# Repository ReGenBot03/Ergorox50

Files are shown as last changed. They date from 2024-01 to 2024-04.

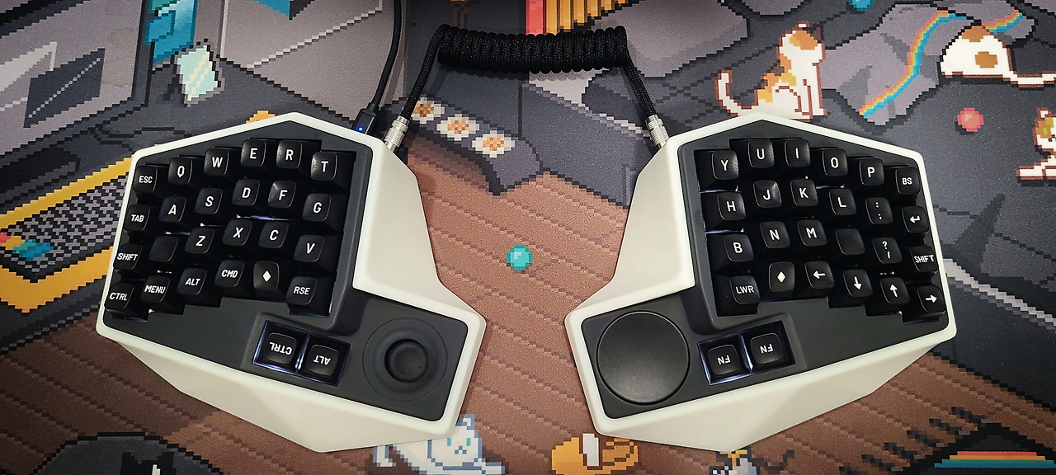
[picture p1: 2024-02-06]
Pics/Title.png

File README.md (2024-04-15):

Title
# ErgoRox50 - Split keyboard with joystick & Trackpad

### Schematic :

Schematics
-------------

### Encloser :

Render
-------------

### BOM :

|Item|Quantity|Link|
|---|---|---|
|minimal-fpc-i2c-pcb*|1|https://github.com/keyboard-magpie/minimal-fpc-i2c-pcb|
|Kailh Joystick|1|https://ko.aliexpress.com/item/32982601039.html|
|Joystick Cap (XBox 360)|1|https://ko.aliexpress.com/item/1005004579062558.html|
|TTC Hotswap Socket|52|https://ko.aliexpress.com/item/1005004922507959.html|
|SK6803 MINI-E 3MA|52|https://ko.aliexpress.com/item/1005003636565847.html|
|SOD123 Diode (1N4148W T4)|53|https://ko.aliexpress.com/item/32921490945.html|
|C Type Socket (Male & Female Set)|2|https://ko.aliexpress.com/item/1005005874481984.html|
|TRRS Socket|2|https://ko.aliexpress.com/item/32860019036.html|
|TRRS Cable|1|https://ko.aliexpress.com/item/1005005658312762.html|
|JST 2.0 PH Wire & Socket (6pin)|6||
|JST 2.0 PH Wire & Socket (2pin)|2||
|Cirque 40mm Curved Trackpad|1||
|FFC Cable (Forward, 0.5mm Pitch)|1|https://ko.aliexpress.com/item/1005006020830114.html|
|MX Switches + Keycaps|52||

##### *Strongly recommend that [minimal-fpc-i2c-pcb] order with assembly service (PCBA) 

##### Please understand that PCBs and enclosers are still in WIP state.
-------------

### Special Thanks to :

My friend Rox for awsome naming

elpekeñin from QMK Discord

pfn0 from QMK Discord

casuanoob from QMK Discord

..and all you guys who loves split keyboards!

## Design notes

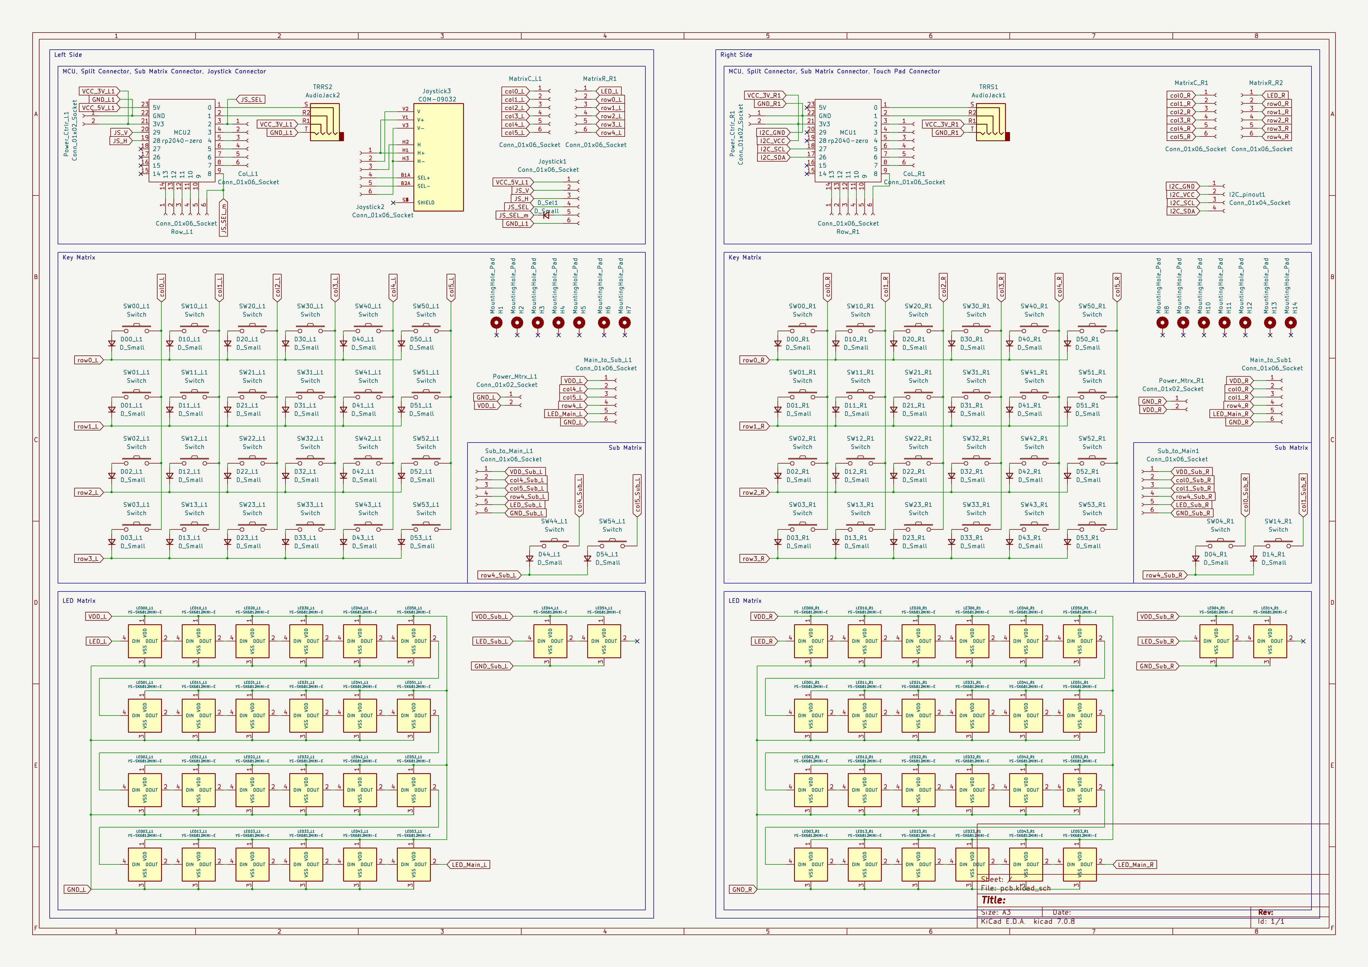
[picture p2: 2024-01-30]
Pics/Schematics.png

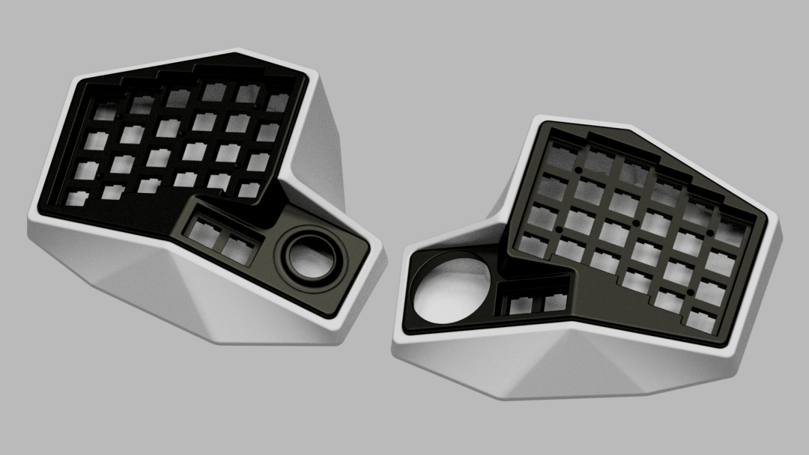
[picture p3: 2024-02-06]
Pics/Render.png

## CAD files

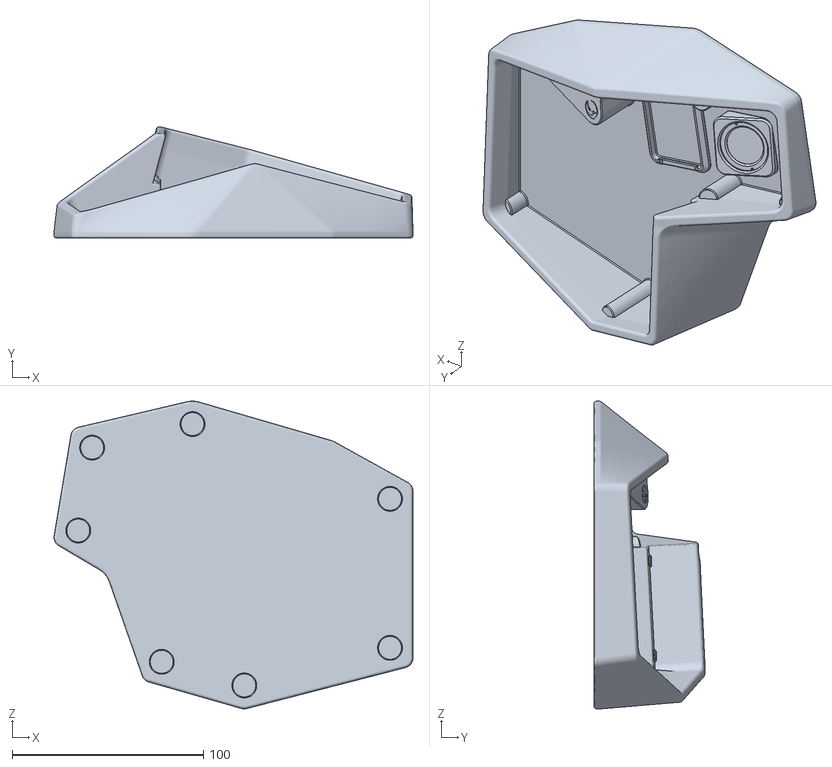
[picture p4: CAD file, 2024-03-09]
STL/240310 ErgoRox50 Lower_R.stl
187.5 x 58.2 x 160.7

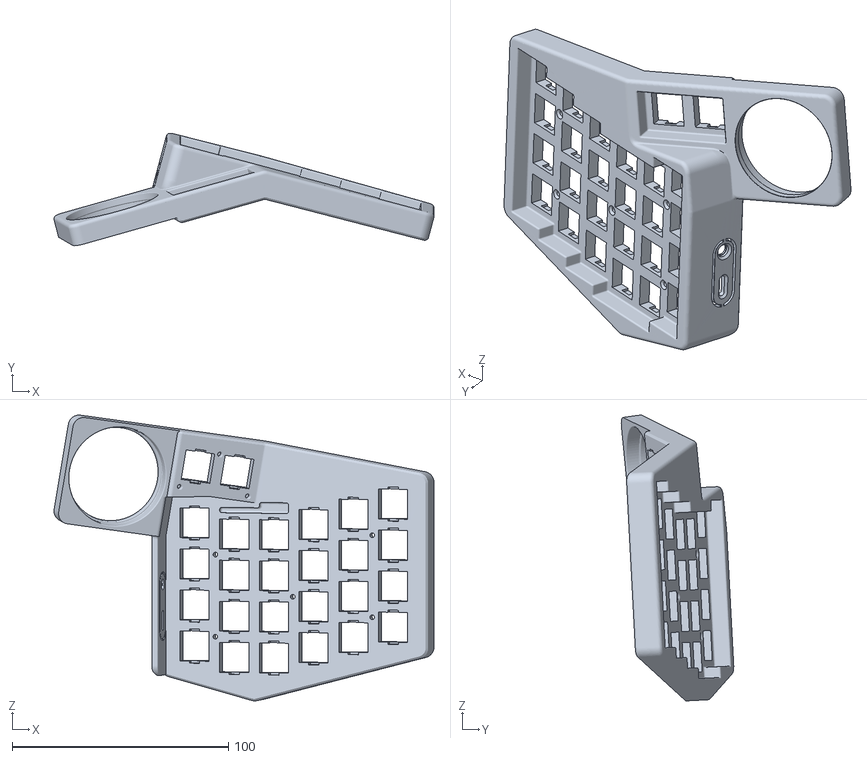
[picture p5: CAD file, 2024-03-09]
STL/240310 ErgoRox50 Upper_R_fixed.stl
175.6 x 52.0 x 132.1

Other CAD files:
STL/240310 ErgoRox50 Lower_L.stl

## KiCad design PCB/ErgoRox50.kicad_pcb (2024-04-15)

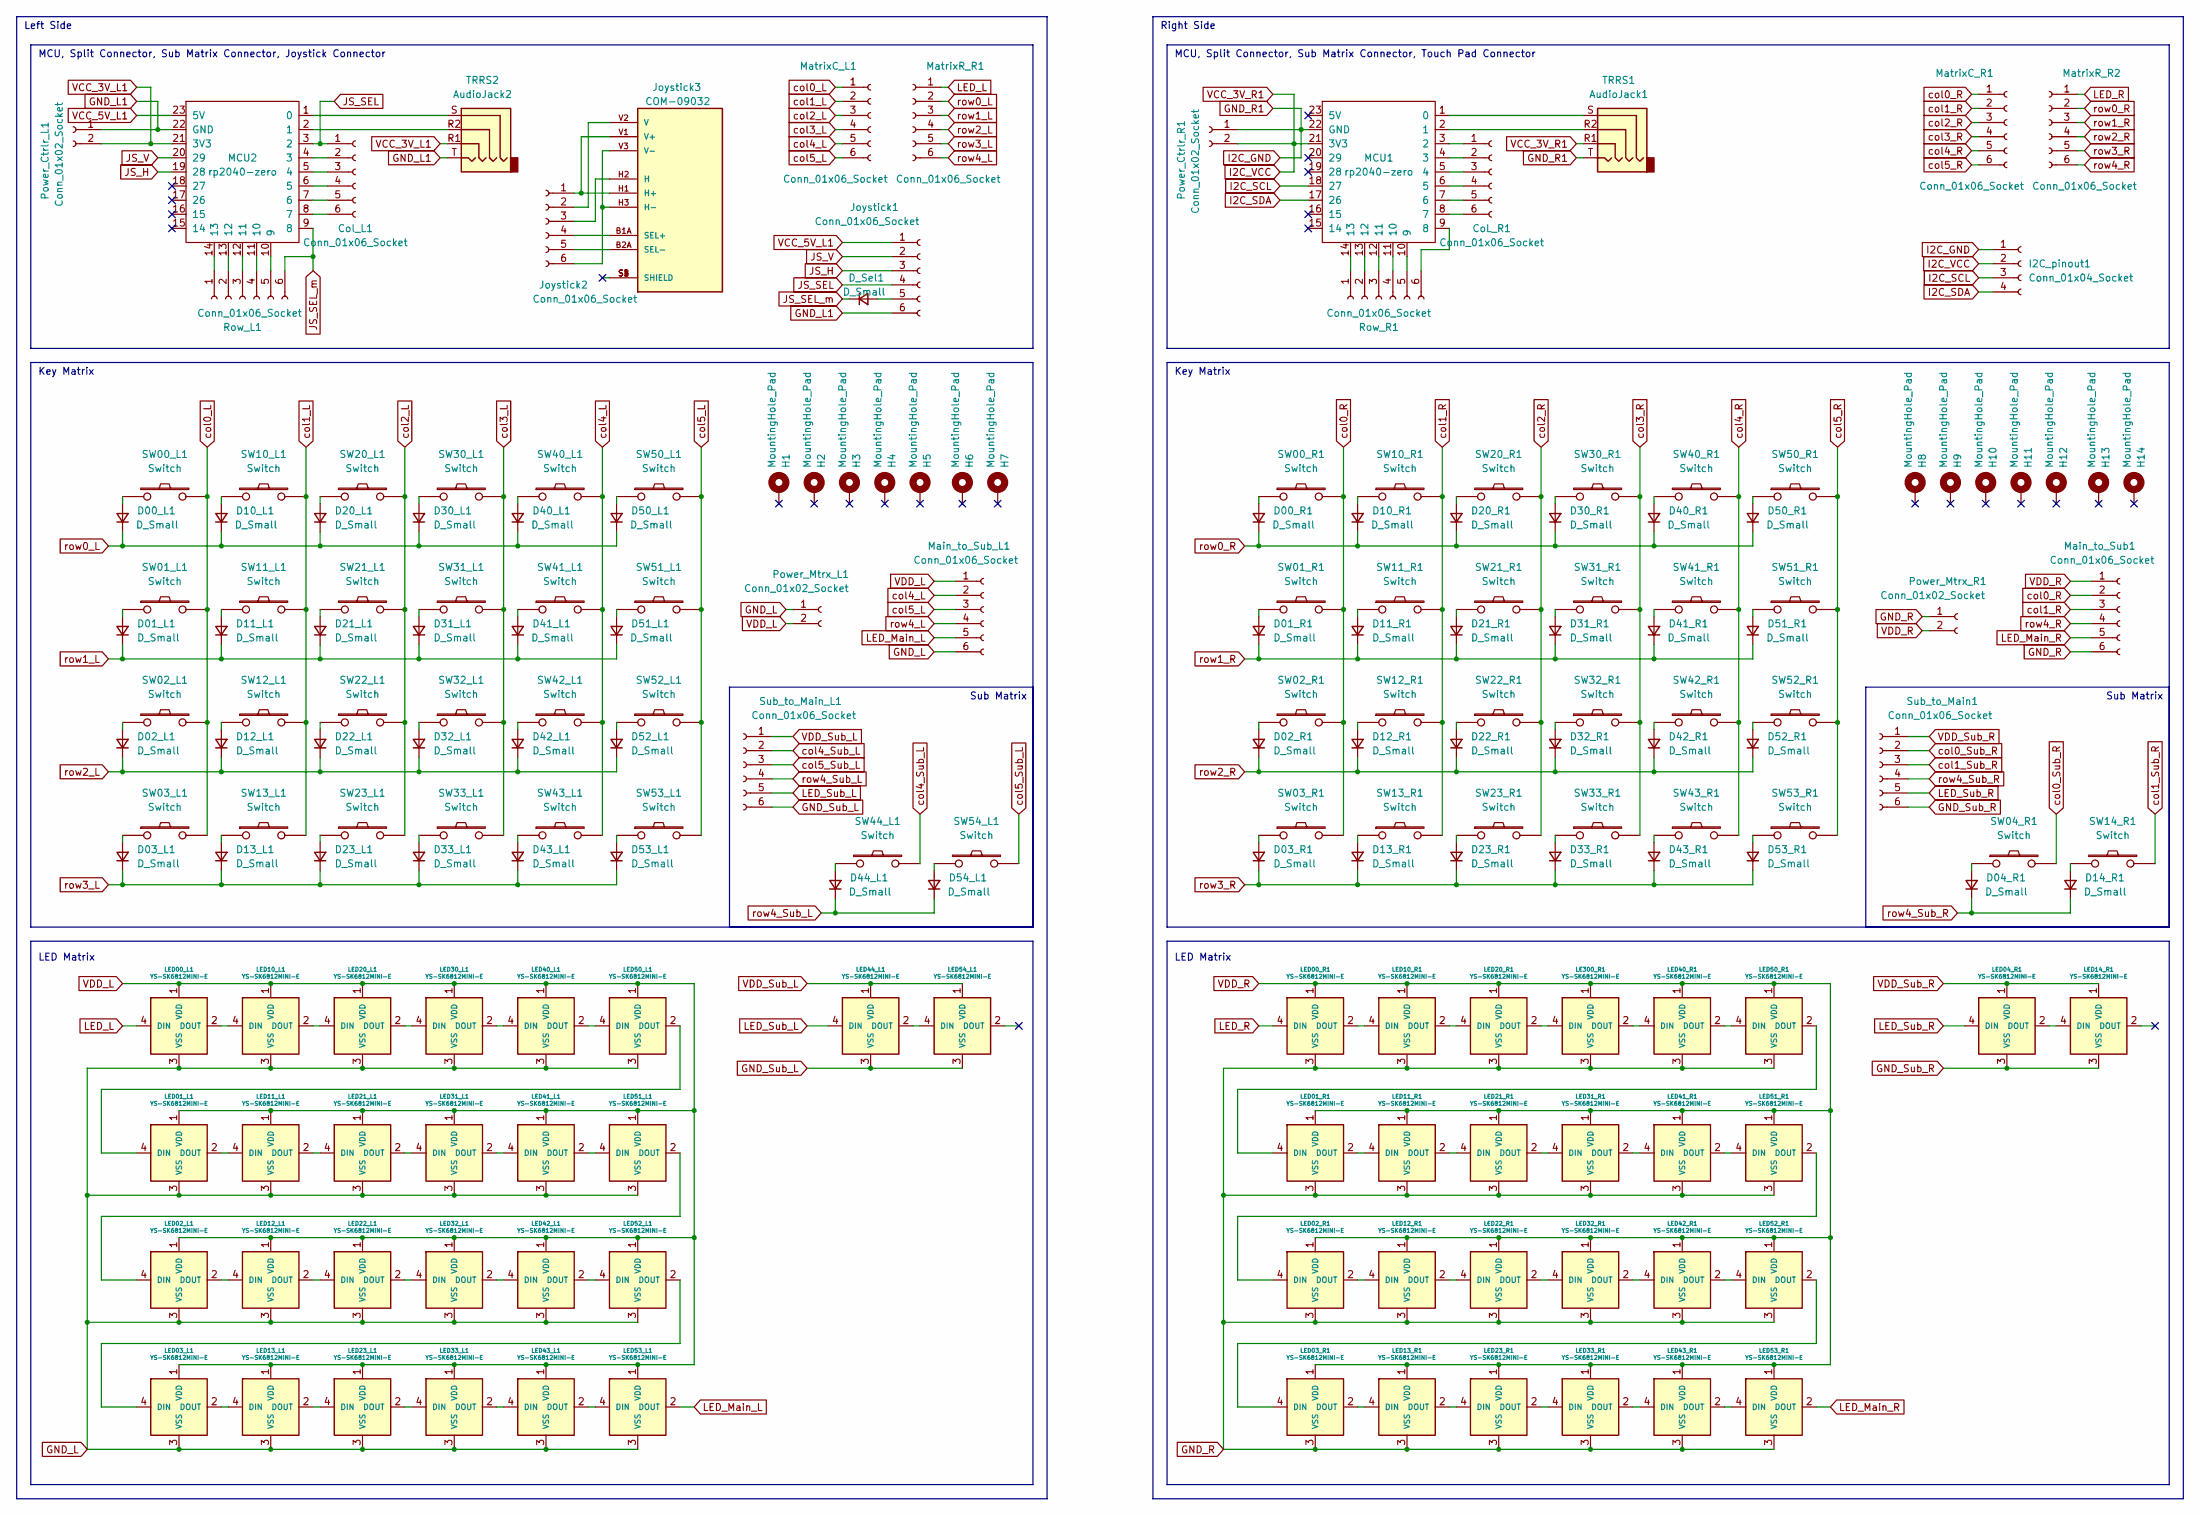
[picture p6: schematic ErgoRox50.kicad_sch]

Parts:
CoL_R1: Conn_01x06_Socket; PinHeader_1x06_P2.00mm_Vertical
Col_L1: Conn_01x06_Socket; PinHeader_1x06_P2.00mm_Vertical
D00_L1, D00_R1, D01_L1, D01_R1, D02_L1, D02_R1, D03_L1, D03_R1, D04_R1, D10_L1, D10_R1, D11_L1, D11_R1, D12_L1, D12_R1, D13_L1, D13_R1, D14_R1, D20_L1, D20_R1, D21_L1, D21_R1, D22_L1, D22_R1, D23_L1, D23_R1, D30_L1, D30_R1, D31_L1, D31_R1, D32_L1, D32_R1, D33_L1, D33_R1, D40_L1, D40_R1, D41_L1, D41_R1, D42_L1, D42_R1, D43_L1, D43_R1, D44_L1, D50_L1, D50_R1, D51_L1, D51_R1, D52_L1, D52_R1, D53_L1, D53_R1, D54_L1: D_Small; D_SOD123
D_Sel1: D_Small; D_SOD123
H1, H2, H3, H4, H5, H6, H7, H8, H9, H10, H11, H12, H13, H14: MountingHole_Pad; MountingHole_2.2mm_M2_DIN965
I2C_pinout1: Conn_01x04_Socket; PinHeader_1x04_P2.00mm_Vertical
Joystick1, Joystick2: Conn_01x06_Socket; PinHeader_1x06_P2.00mm_Vertical
Joystick3: COM-09032; XDCR_COM-09032; PARTREV N/A
LE300_R1: YS-SK6812MINI-E; SK6812-MINI-E
LED00_L1, LED00_R1, LED01_L1, LED01_R1, LED02_L1, LED02_R1, LED03_L1, LED03_R1, LED04_R1, LED10_L1, LED10_R1, LED11_L1, LED11_R1, LED12_L1, LED12_R1, LED13_L1, LED13_R1, LED14_R1, LED20_L1, LED20_R1, LED21_L1, LED21_R1, LED22_L1, LED22_R1, LED23_L1, LED23_R1, LED30_L1, LED31_L1, LED31_R1, LED32_L1, LED32_R1, LED33_L1, LED33_R1, LED40_L1, LED40_R1, LED41_L1, LED41_R1, LED42_L1, LED42_R1, LED43_L1, LED43_R1, LED44_L1, LED50_L1, LED50_R1, LED51_L1, LED51_R1, LED52_L1, LED52_R1, LED53_L1, LED53_R1, LED54_L1: YS-SK6812MINI-E; SK6812-MINI-E
MCU1, MCU2: rp2040-zero; rp2040-zero-tht-pads-cutout
Main_to_Sub1: Conn_01x06_Socket; PinHeader_1x06_P2.00mm_Vertical
Main_to_Sub_L1: Conn_01x06_Socket; PinHeader_1x06_P2.00mm_Vertical
MatrixC_L1: Conn_01x06_Socket; PinHeader_1x06_P2.00mm_Vertical
MatrixC_R1: Conn_01x06_Socket; PinHeader_1x06_P2.00mm_Vertical
MatrixR_R1, MatrixR_R2: Conn_01x06_Socket; PinHeader_1x06_P2.00mm_Vertical
Power_Ctrlr_L1: Conn_01x02_Socket; PinHeader_1x02_P2.00mm_Vertical
Power_Ctrlr_R1: Conn_01x02_Socket; PinHeader_1x02_P2.00mm_Vertical
Power_Mtrx_L1: Conn_01x02_Socket; PinHeader_1x02_P2.00mm_Vertical
Power_Mtrx_R1: Conn_01x02_Socket; PinHeader_1x02_P2.00mm_Vertical
Row_L1: Conn_01x06_Socket; PinHeader_1x06_P2.00mm_Vertical
Row_R1: Conn_01x06_Socket; PinHeader_1x06_P2.00mm_Vertical
SW00_L1, SW00_R1, SW01_L1, SW01_R1, SW02_L1, SW02_R1, SW03_L1, SW03_R1, SW04_R1, SW10_L1, SW10_R1, SW11_L1, SW11_R1, SW12_L1, SW12_R1, SW13_L1, SW13_R1, SW14_R1, SW20_L1, SW20_R1, SW21_L1, SW21_R1, SW22_L1, SW22_R1, SW23_L1, SW23_R1, SW30_L1, SW30_R1, SW31_L1, SW31_R1, SW32_L1, SW32_R1, SW33_L1, SW33_R1, SW40_L1, SW40_R1, SW41_L1, SW41_R1, SW42_L1, SW42_R1, SW43_L1, SW43_R1, SW44_L1, SW50_L1, SW50_R1, SW51_L1, SW51_R1, SW52_L1, SW52_R1, SW53_L1, SW53_R1, SW54_L1: Switch; Kailh_socket_MX
Sub_to_Main1: Conn_01x06_Socket; PinHeader_1x06_P2.00mm_Vertical
Sub_to_Main_L1: Conn_01x06_Socket; PinHeader_1x06_P2.00mm_Vertical
TRRS1: AudioJack1; TRRS-PJ-320A-no-Fmask
TRRS2: AudioJack2; TRRS-PJ-320A-no-Fmask

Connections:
GND_L: LED00_L1.3 (VSS), LED01_L1.3 (VSS), LED02_L1.3 (VSS), LED03_L1.3 (VSS), LED10_L1.3 (VSS), LED11_L1.3 (VSS), LED12_L1.3 (VSS), LED13_L1.3 (VSS), LED20_L1.3 (VSS), LED21_L1.3 (VSS), LED22_L1.3 (VSS), LED23_L1.3 (VSS), LED30_L1.3 (VSS), LED31_L1.3 (VSS), LED32_L1.3 (VSS), LED33_L1.3 (VSS), LED40_L1.3 (VSS), LED41_L1.3 (VSS), LED42_L1.3 (VSS), LED43_L1.3 (VSS), LED50_L1.3 (VSS), LED51_L1.3 (VSS), LED52_L1.3 (VSS), LED53_L1.3 (VSS), Main_to_Sub_L1.6, Power_Mtrx_L1.1
GND_L1: Joystick1.6, MCU2.22 (GND), Power_Ctrlr_L1.1, TRRS2.T
GND_R: LE300_R1.3 (VSS), LED00_R1.3 (VSS), LED01_R1.3 (VSS), LED02_R1.3 (VSS), LED03_R1.3 (VSS), LED10_R1.3 (VSS), LED11_R1.3 (VSS), LED12_R1.3 (VSS), LED13_R1.3 (VSS), LED20_R1.3 (VSS), LED21_R1.3 (VSS), LED22_R1.3 (VSS), LED23_R1.3 (VSS), LED31_R1.3 (VSS), LED32_R1.3 (VSS), LED33_R1.3 (VSS), LED40_R1.3 (VSS), LED41_R1.3 (VSS), LED42_R1.3 (VSS), LED43_R1.3 (VSS), LED50_R1.3 (VSS), LED51_R1.3 (VSS), LED52_R1.3 (VSS), LED53_R1.3 (VSS), Main_to_Sub1.6, Power_Mtrx_R1.1
GND_R1: I2C_pinout1.1, MCU1.22 (GND), Power_Ctrlr_R1.1, TRRS1.T
GND_Sub_L: LED44_L1.3 (VSS), LED54_L1.3 (VSS), Sub_to_Main_L1.6
GND_Sub_R: LED04_R1.3 (VSS), LED14_R1.3 (VSS), Sub_to_Main1.6
I2C_SCL: I2C_pinout1.3, MCU1.18 (27)
I2C_SDA: I2C_pinout1.4, MCU1.17 (26)
I2C_VCC: I2C_pinout1.2, MCU1.21 (3V3), Power_Ctrlr_R1.2, TRRS1.R1
JS_H: Joystick1.3, MCU2.19 (28)
JS_SEL: Col_L1.1, Joystick1.4, MCU2.3 (2)
JS_SEL_m: D_Sel1.1 (K), MCU2.9 (8), Row_L1.6
JS_V: Joystick1.2, MCU2.20 (29)
LED_L: LED00_L1.4 (DIN), MatrixR_R1.1
LED_Main_L: LED53_L1.2 (DOUT), Main_to_Sub_L1.5
LED_Main_R: LED53_R1.2 (DOUT), Main_to_Sub1.5
LED_R: LED00_R1.4 (DIN), MatrixR_R2.1
LED_Sub_L: LED44_L1.4 (DIN), Sub_to_Main_L1.5
LED_Sub_R: LED04_R1.4 (DIN), Sub_to_Main1.5
unnamed: CoL_R1.1, MCU1.3 (2)
unnamed: CoL_R1.2, MCU1.4 (3)
unnamed: CoL_R1.3, MCU1.5 (4)
unnamed: CoL_R1.4, MCU1.6 (5)
unnamed: CoL_R1.5, MCU1.7 (6)
unnamed: CoL_R1.6, MCU1.8 (7)
unnamed: Col_L1.2, MCU2.4 (3)
unnamed: Col_L1.3, MCU2.5 (4)
unnamed: Col_L1.4, MCU2.6 (5)
unnamed: Col_L1.5, MCU2.7 (6)
unnamed: Col_L1.6, MCU2.8 (7)
unnamed: D00_L1.2 (A), SW00_L1.1
unnamed: D00_R1.2 (A), SW00_R1.1
unnamed: D01_L1.2 (A), SW01_L1.1
unnamed: D01_R1.2 (A), SW01_R1.1
unnamed: D02_L1.2 (A), SW02_L1.1
unnamed: D02_R1.2 (A), SW02_R1.1
unnamed: D03_L1.2 (A), SW03_L1.1
unnamed: D03_R1.2 (A), SW03_R1.1
unnamed: D04_R1.2 (A), SW04_R1.1
unnamed: D10_L1.2 (A), SW10_L1.1
unnamed: D10_R1.2 (A), SW10_R1.1
unnamed: D11_L1.2 (A), SW11_L1.1
unnamed: D11_R1.2 (A), SW11_R1.1
unnamed: D12_L1.2 (A), SW12_L1.1
unnamed: D12_R1.2 (A), SW12_R1.1
unnamed: D13_L1.2 (A), SW13_L1.1
unnamed: D13_R1.2 (A), SW13_R1.1
unnamed: D14_R1.2 (A), SW14_R1.1
unnamed: D20_L1.2 (A), SW20_L1.1
unnamed: D20_R1.2 (A), SW20_R1.1
unnamed: D21_L1.2 (A), SW21_L1.1
unnamed: D21_R1.2 (A), SW21_R1.1
unnamed: D22_L1.2 (A), SW22_L1.1
unnamed: D22_R1.2 (A), SW22_R1.1
unnamed: D23_L1.2 (A), SW23_L1.1
unnamed: D23_R1.2 (A), SW23_R1.1
unnamed: D30_L1.2 (A), SW30_L1.1
unnamed: D30_R1.2 (A), SW30_R1.1
unnamed: D31_L1.2 (A), SW31_L1.1
unnamed: D31_R1.2 (A), SW31_R1.1
unnamed: D32_L1.2 (A), SW32_L1.1
unnamed: D32_R1.2 (A), SW32_R1.1
unnamed: D33_L1.2 (A), SW33_L1.1
unnamed: D33_R1.2 (A), SW33_R1.1
unnamed: D40_L1.2 (A), SW40_L1.1
unnamed: D40_R1.2 (A), SW40_R1.1
unnamed: D41_L1.2 (A), SW41_L1.1
unnamed: D41_R1.2 (A), SW41_R1.1
unnamed: D42_L1.2 (A), SW42_L1.1
unnamed: D42_R1.2 (A), SW42_R1.1
unnamed: D43_L1.2 (A), SW43_L1.1
unnamed: D43_R1.2 (A), SW43_R1.1
unnamed: D44_L1.2 (A), SW44_L1.1
unnamed: D50_L1.2 (A), SW50_L1.1
unnamed: D50_R1.2 (A), SW50_R1.1
unnamed: D51_L1.2 (A), SW51_L1.1
unnamed: D51_R1.2 (A), SW51_R1.1
unnamed: D52_L1.2 (A), SW52_L1.1
unnamed: D52_R1.2 (A), SW52_R1.1
unnamed: D53_L1.2 (A), SW53_L1.1
unnamed: D53_R1.2 (A), SW53_R1.1
unnamed: D54_L1.2 (A), SW54_L1.1
unnamed: D_Sel1.2 (A), Joystick1.5
unnamed: Joystick2.1, Joystick3.H1 (H+), Joystick3.V1 (V+)
unnamed: Joystick2.2, Joystick3.V2 (V)
unnamed: Joystick2.3, Joystick3.H2 (H)
unnamed: Joystick2.4, Joystick3.B1A (SEL+)
unnamed: Joystick2.5, Joystick3.B2A (SEL-)
unnamed: Joystick2.6, Joystick3.H3 (H-), Joystick3.V3 (V-)
unnamed: LE300_R1.4 (DIN), LED20_R1.2 (DOUT)
unnamed: LE300_R1.2 (DOUT), LED40_R1.4 (DIN)
unnamed: LED00_L1.2 (DOUT), LED10_L1.4 (DIN)
unnamed: LED00_R1.2 (DOUT), LED10_R1.4 (DIN)
unnamed: LED01_L1.4 (DIN), LED50_L1.2 (DOUT)
unnamed: LED01_L1.2 (DOUT), LED11_L1.4 (DIN)
unnamed: LED01_R1.4 (DIN), LED50_R1.2 (DOUT)
unnamed: LED01_R1.2 (DOUT), LED11_R1.4 (DIN)
unnamed: LED02_L1.4 (DIN), LED51_L1.2 (DOUT)
unnamed: LED02_L1.2 (DOUT), LED12_L1.4 (DIN)
unnamed: LED02_R1.4 (DIN), LED51_R1.2 (DOUT)
unnamed: LED02_R1.2 (DOUT), LED12_R1.4 (DIN)
unnamed: LED03_L1.4 (DIN), LED52_L1.2 (DOUT)
unnamed: LED03_L1.2 (DOUT), LED13_L1.4 (DIN)
unnamed: LED03_R1.4 (DIN), LED52_R1.2 (DOUT)
unnamed: LED03_R1.2 (DOUT), LED13_R1.4 (DIN)
unnamed: LED04_R1.2 (DOUT), LED14_R1.4 (DIN)
unnamed: LED10_L1.2 (DOUT), LED20_L1.4 (DIN)
unnamed: LED10_R1.2 (DOUT), LED20_R1.4 (DIN)
unnamed: LED11_L1.2 (DOUT), LED21_L1.4 (DIN)
unnamed: LED11_R1.2 (DOUT), LED21_R1.4 (DIN)
unnamed: LED12_L1.2 (DOUT), LED22_L1.4 (DIN)
unnamed: LED12_R1.2 (DOUT), LED22_R1.4 (DIN)
unnamed: LED13_L1.2 (DOUT), LED23_L1.4 (DIN)
unnamed: LED13_R1.2 (DOUT), LED23_R1.4 (DIN)
unnamed: LED20_L1.2 (DOUT), LED30_L1.4 (DIN)
unnamed: LED21_L1.2 (DOUT), LED31_L1.4 (DIN)
unnamed: LED21_R1.2 (DOUT), LED31_R1.4 (DIN)
unnamed: LED22_L1.2 (DOUT), LED32_L1.4 (DIN)
unnamed: LED22_R1.2 (DOUT), LED32_R1.4 (DIN)
unnamed: LED23_L1.2 (DOUT), LED33_L1.4 (DIN)
unnamed: LED23_R1.2 (DOUT), LED33_R1.4 (DIN)
unnamed: LED30_L1.2 (DOUT), LED40_L1.4 (DIN)
unnamed: LED31_L1.2 (DOUT), LED41_L1.4 (DIN)
unnamed: LED31_R1.2 (DOUT), LED41_R1.4 (DIN)
unnamed: LED32_L1.2 (DOUT), LED42_L1.4 (DIN)
unnamed: LED32_R1.2 (DOUT), LED42_R1.4 (DIN)
unnamed: LED33_L1.2 (DOUT), LED43_L1.4 (DIN)
unnamed: LED33_R1.2 (DOUT), LED43_R1.4 (DIN)
unnamed: LED40_L1.2 (DOUT), LED50_L1.4 (DIN)
unnamed: LED40_R1.2 (DOUT), LED50_R1.4 (DIN)
unnamed: LED41_L1.2 (DOUT), LED51_L1.4 (DIN)
unnamed: LED41_R1.2 (DOUT), LED51_R1.4 (DIN)
unnamed: LED42_L1.2 (DOUT), LED52_L1.4 (DIN)
unnamed: LED42_R1.2 (DOUT), LED52_R1.4 (DIN)
unnamed: LED43_L1.2 (DOUT), LED53_L1.4 (DIN)
unnamed: LED43_R1.2 (DOUT), LED53_R1.4 (DIN)
unnamed: LED44_L1.2 (DOUT), LED54_L1.4 (DIN)
unnamed: MCU1.1 (0), TRRS1.S
unnamed: MCU1.2 (1), TRRS1.R2
unnamed: MCU1.9 (8), Row_R1.6
unnamed: MCU1.10 (9), Row_R1.5
unnamed: MCU1.11 (10), Row_R1.4
unnamed: MCU1.12 (11), Row_R1.3
unnamed: MCU1.13 (12), Row_R1.2
unnamed: MCU1.14 (13), Row_R1.1
unnamed: MCU2.1 (0), TRRS2.S
unnamed: MCU2.2 (1), TRRS2.R2
unnamed: MCU2.10 (9), Row_L1.5
unnamed: MCU2.11 (10), Row_L1.4
unnamed: MCU2.12 (11), Row_L1.3
unnamed: MCU2.13 (12), Row_L1.2
unnamed: MCU2.14 (13), Row_L1.1
VCC_3V_L1: MCU2.21 (3V3), Power_Ctrlr_L1.2, TRRS2.R1
VCC_5V_L1: Joystick1.1, MCU2.23 (5V)
VDD_L: LED00_L1.1 (VDD), LED01_L1.1 (VDD), LED02_L1.1 (VDD), LED03_L1.1 (VDD), LED10_L1.1 (VDD), LED11_L1.1 (VDD), LED12_L1.1 (VDD), LED13_L1.1 (VDD), LED20_L1.1 (VDD), LED21_L1.1 (VDD), LED22_L1.1 (VDD), LED23_L1.1 (VDD), LED30_L1.1 (VDD), LED31_L1.1 (VDD), LED32_L1.1 (VDD), LED33_L1.1 (VDD), LED40_L1.1 (VDD), LED41_L1.1 (VDD), LED42_L1.1 (VDD), LED43_L1.1 (VDD), LED50_L1.1 (VDD), LED51_L1.1 (VDD), LED52_L1.1 (VDD), LED53_L1.1 (VDD), Main_to_Sub_L1.1, Power_Mtrx_L1.2
VDD_R: LE300_R1.1 (VDD), LED00_R1.1 (VDD), LED01_R1.1 (VDD), LED02_R1.1 (VDD), LED03_R1.1 (VDD), LED10_R1.1 (VDD), LED11_R1.1 (VDD), LED12_R1.1 (VDD), LED13_R1.1 (VDD), LED20_R1.1 (VDD), LED21_R1.1 (VDD), LED22_R1.1 (VDD), LED23_R1.1 (VDD), LED31_R1.1 (VDD), LED32_R1.1 (VDD), LED33_R1.1 (VDD), LED40_R1.1 (VDD), LED41_R1.1 (VDD), LED42_R1.1 (VDD), LED43_R1.1 (VDD), LED50_R1.1 (VDD), LED51_R1.1 (VDD), LED52_R1.1 (VDD), LED53_R1.1 (VDD), Main_to_Sub1.1, Power_Mtrx_R1.2
VDD_Sub_L: LED44_L1.1 (VDD), LED54_L1.1 (VDD), Sub_to_Main_L1.1
VDD_Sub_R: LED04_R1.1 (VDD), LED14_R1.1 (VDD), Sub_to_Main1.1
col0_L: MatrixC_L1.1, SW00_L1.2, SW01_L1.2, SW02_L1.2, SW03_L1.2
col0_R: Main_to_Sub1.2, MatrixC_R1.1, SW00_R1.2, SW01_R1.2, SW02_R1.2, SW03_R1.2
col0_Sub_R: SW04_R1.2, Sub_to_Main1.2
col1_L: MatrixC_L1.2, SW10_L1.2, SW11_L1.2, SW12_L1.2, SW13_L1.2
col1_R: Main_to_Sub1.3, MatrixC_R1.2, SW10_R1.2, SW11_R1.2, SW12_R1.2, SW13_R1.2
col1_Sub_R: SW14_R1.2, Sub_to_Main1.3
col2_L: MatrixC_L1.3, SW20_L1.2, SW21_L1.2, SW22_L1.2, SW23_L1.2
col2_R: MatrixC_R1.3, SW20_R1.2, SW21_R1.2, SW22_R1.2, SW23_R1.2
col3_L: MatrixC_L1.4, SW30_L1.2, SW31_L1.2, SW32_L1.2, SW33_L1.2
col3_R: MatrixC_R1.4, SW30_R1.2, SW31_R1.2, SW32_R1.2, SW33_R1.2
col4_L: Main_to_Sub_L1.2, MatrixC_L1.5, SW40_L1.2, SW41_L1.2, SW42_L1.2, SW43_L1.2
col4_R: MatrixC_R1.5, SW40_R1.2, SW41_R1.2, SW42_R1.2, SW43_R1.2
col4_Sub_L: SW44_L1.2, Sub_to_Main_L1.2
col5_L: Main_to_Sub_L1.3, MatrixC_L1.6, SW50_L1.2, SW51_L1.2, SW52_L1.2, SW53_L1.2
col5_R: MatrixC_R1.6, SW50_R1.2, SW51_R1.2, SW52_R1.2, SW53_R1.2
col5_Sub_L: SW54_L1.2, Sub_to_Main_L1.3
row0_L: D00_L1.1 (K), D10_L1.1 (K), D20_L1.1 (K), D30_L1.1 (K), D40_L1.1 (K), D50_L1.1 (K), MatrixR_R1.2
row0_R: D00_R1.1 (K), D10_R1.1 (K), D20_R1.1 (K), D30_R1.1 (K), D40_R1.1 (K), D50_R1.1 (K), MatrixR_R2.2
row1_L: D01_L1.1 (K), D11_L1.1 (K), D21_L1.1 (K), D31_L1.1 (K), D41_L1.1 (K), D51_L1.1 (K), MatrixR_R1.3
row1_R: D01_R1.1 (K), D11_R1.1 (K), D21_R1.1 (K), D31_R1.1 (K), D41_R1.1 (K), D51_R1.1 (K), MatrixR_R2.3
row2_L: D02_L1.1 (K), D12_L1.1 (K), D22_L1.1 (K), D32_L1.1 (K), D42_L1.1 (K), D52_L1.1 (K), MatrixR_R1.4
row2_R: D02_R1.1 (K), D12_R1.1 (K), D22_R1.1 (K), D32_R1.1 (K), D42_R1.1 (K), D52_R1.1 (K), MatrixR_R2.4
row3_L: D03_L1.1 (K), D13_L1.1 (K), D23_L1.1 (K), D33_L1.1 (K), D43_L1.1 (K), D53_L1.1 (K), MatrixR_R1.5
row3_R: D03_R1.1 (K), D13_R1.1 (K), D23_R1.1 (K), D33_R1.1 (K), D43_R1.1 (K), D53_R1.1 (K), MatrixR_R2.5
row4_L: Main_to_Sub_L1.4, MatrixR_R1.6
row4_R: Main_to_Sub1.4, MatrixR_R2.6
row4_Sub_L: D44_L1.1 (K), D54_L1.1 (K), Sub_to_Main_L1.4
row4_Sub_R: D04_R1.1 (K), D14_R1.1 (K), Sub_to_Main1.4

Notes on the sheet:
Sub Matrix
Right Side
LED Matrix
Left Side
MCU, Split Connector, Sub Matrix Connector, Joystick Connector
Key Matrix
MCU, Split Connector, Sub Matrix Connector, Touch Pad Connector

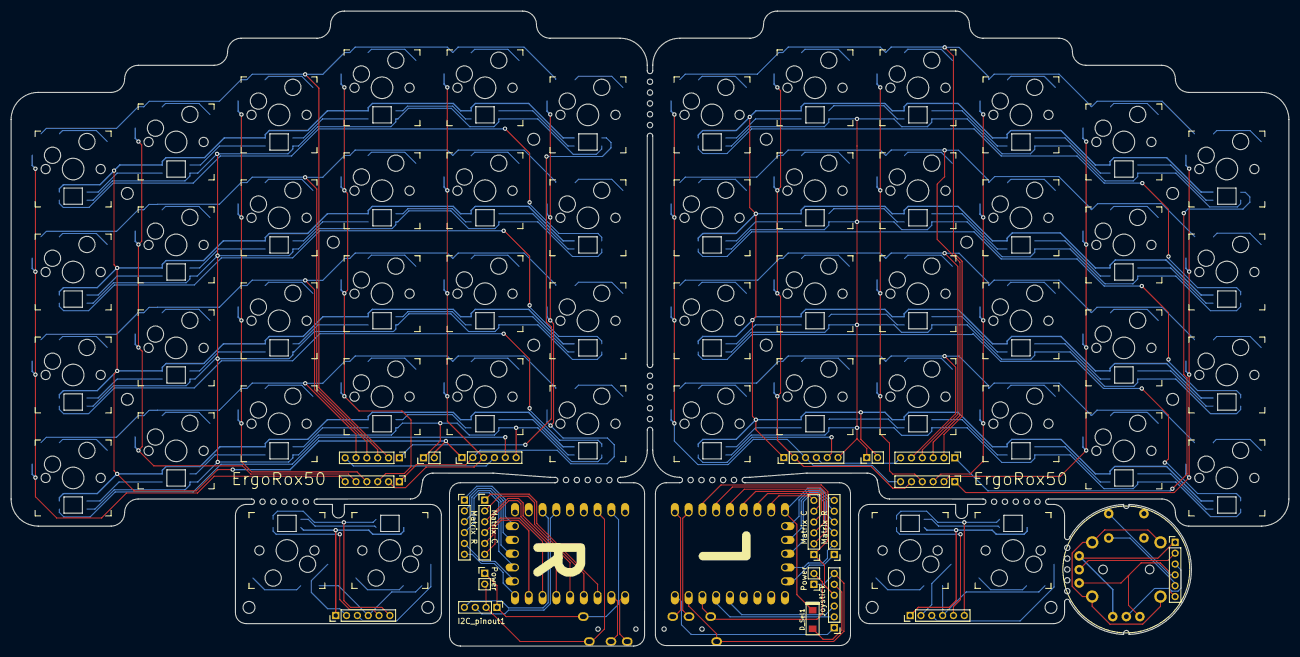
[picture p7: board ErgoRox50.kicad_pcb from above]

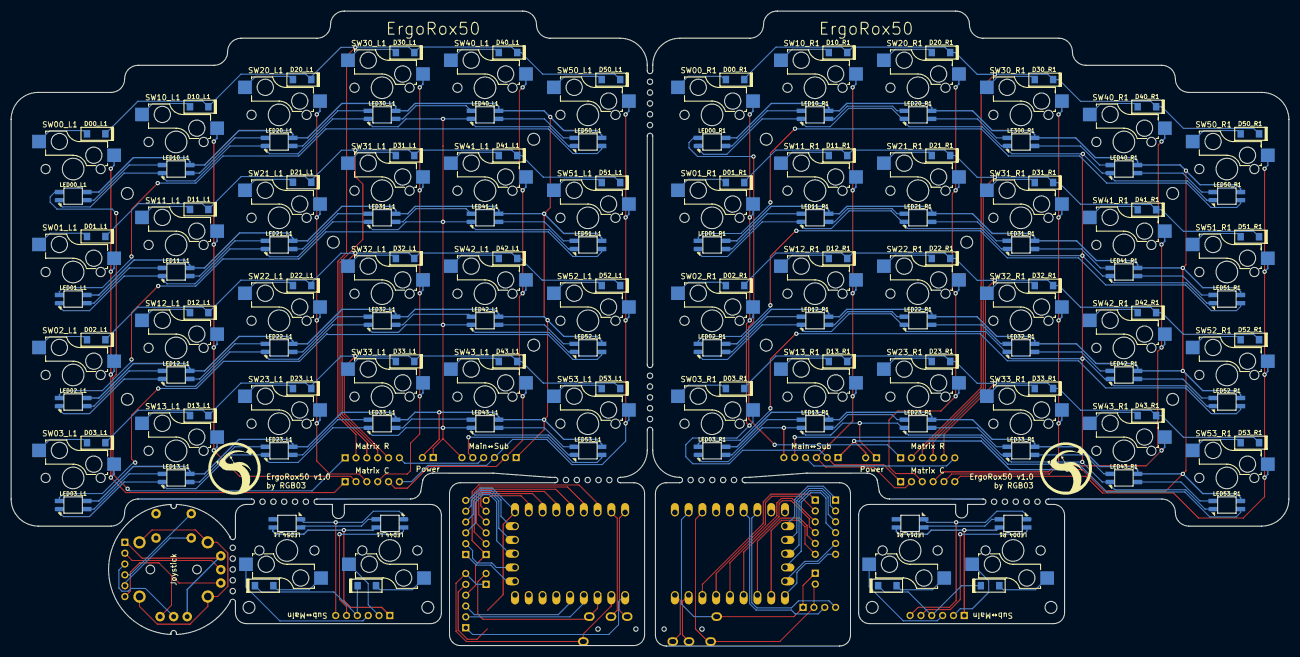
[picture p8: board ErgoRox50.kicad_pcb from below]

Board: 2 copper layers, 235.8 x 117.2 mm, 197 parts (106 on the bottom side), 186 nets.

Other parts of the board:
ProjectOrtholi: LOGO; Ortholi_logo_mini
ProjectOrtholi#2: LOGO; Ortholi_logo_mini

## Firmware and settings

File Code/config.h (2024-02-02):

#pragma once

/* Key Matrix */
#define MATRIX_ROW_PINS { GP12, GP11, GP10, GP9, GP8 }
#define MATRIX_COL_PINS { GP7, GP6, GP5, GP4, GP3, GP2 }
#define RGB_DI_PIN GP13
#define DRIVER_LED_TOTAL 52

/* I2C Driver Settings */
#define I2C_DRIVER I2CD1
#define I2C1_SDA_PIN GP26
#define I2C1_SCL_PIN GP27

/* Split parameters */
#define MASTER_LEFT
#define SERIAL_USART_FULL_DUPLEX
#define SERIAL_USART_TX_PIN GP0
#define SERIAL_USART_RX_PIN GP1
#define SERIAL_USART_PIN_SWAP
#define SPLIT_USB_DETECT
#define SPLIT_USB_TIMEOUT 2500
#define SPLIT_WATCHDOG_ENABLE
#define SPLIT_LAYER_STATE_ENABLE
#define SPLIT_POINTING_ENABLE

/* Right Thumb Device Settings - CirquePad */
#define POINTING_DEVICE_RIGHT
#define POINTING_DEVICE_ROTATION_90
#define CIRQUE_PINNACLE_ADDR 0x2A
#define CIRQUE_PINNACLE_DIAMETER_MM 40
#define CIRQUE_PINNACLE_CURVED_OVERLAY
#define CIRQUE_PINNACLE_TAP_ENABLE
#define POINTING_DEVICE_GESTURES_SCROLL_ENABLE
#define POINTING_DEVICE_GESTURES_CURSOR_GLIDE_ENABLE
#define CIRQUE_PINNACLE_POSITION_MODE CIRQUE_PINNACLE_RELATIVE_MODE
#define CIRQUE_PINNACLE_ATTENUATION EXTREG__TRACK_ADCCONFIG__ADC_ATTENUATE_2X

/* Left Thumb Device Settings - Joystick */
#define JS_X_PIN GP28
#define JS_Y_PIN GP29
#define JS_X_MID 720
#define JS_Y_MID 755
#define JS_DEAD 200
#define MOUSEKEY_MAX_SPEED 8
#define MOUSEKEY_WHEEL_MAX_SPEED 5

/* RGB Backlight */
#define NOP_FUDGE 0.4
#ifdef RGBLIGHT_ENABLE
#    define RGB_MATRIX_SPLIT    { 26, 26 }
#    define SPLIT_TRANSPORT_MIRROR
#    define RGBLIGHT_EFFECT_BREATHING
#    define RGBLIGHT_EFFECT_RAINBOW_MOOD
#    define RGBLIGHT_EFFECT_RAINBOW_SWIRL
#    define RGBLIGHT_EFFECT_KNIGHT
#    define RGBLIGHT_EFFECT_STATIC_GRADIENT
#    define RGBLIGHT_EFFECT_TWINKLE
#    define RGBLIGHT_EFFECT_RGB_TEST
#endif
